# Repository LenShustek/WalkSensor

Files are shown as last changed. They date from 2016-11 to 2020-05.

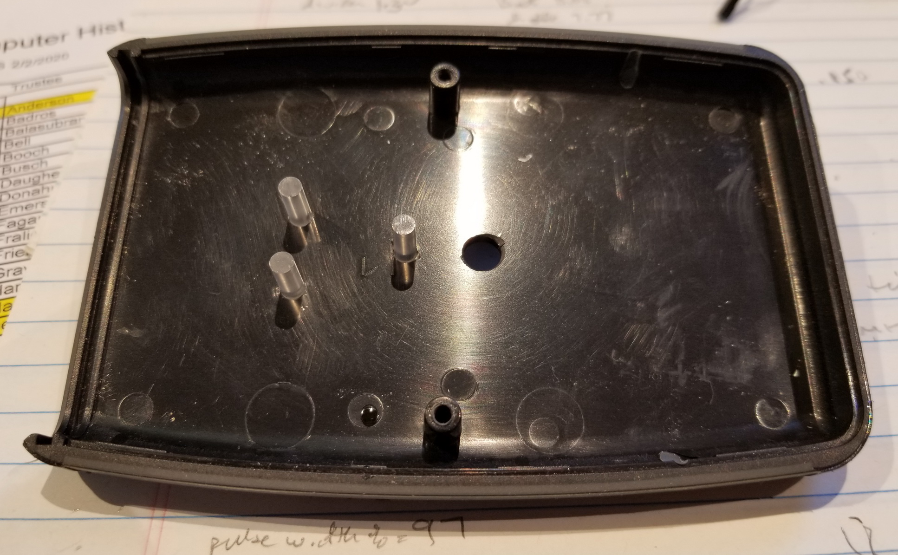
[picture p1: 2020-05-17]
V3/cover.jpg

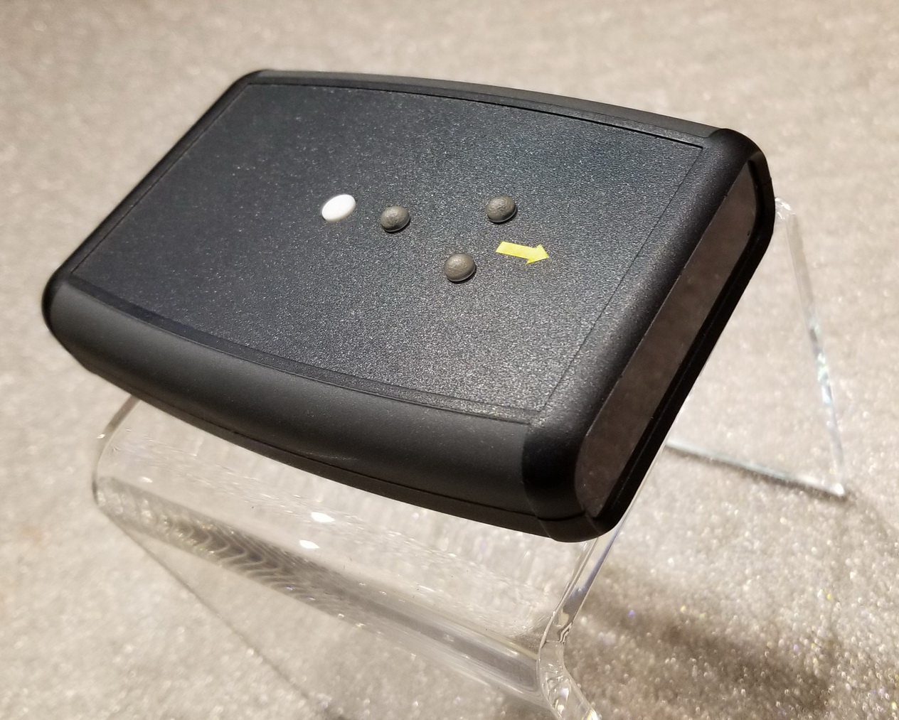
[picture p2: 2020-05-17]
V3/outside_sm.jpg

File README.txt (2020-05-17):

           Battery-powered walk path sensor
 for clinical trials of therapies for movement disorders

  This is a small battery-powered wireless sensor that, when used
  in a pair on opposite sides of a walking path, detects someone
  walking through an IR beam between the sensors. It then sends a
  Bluetooth alert with detailed timing to a mobile phone or tablet.

  The custom-built sensor hardware consist of:
  - an AVR microprocessor
  - a Bluetooth LE radio module
  - 940nm IR LED transmitter powered by a constant-current driver
  - 940nm 38 Khz tuned IR receiver
  - red/green battery status light
  - blue and yellow operational status lights
  - power on/off pushbutton
  - program-controlled power supply circuit
  - enclosure with battery holder

Version 2 in 2017 used the Adafruit Bluefruit Feather 32U4 with an 
integrated Bluetooth module. The board used mostly through-hole 
components, and required tricky alignment of the LEDs into holes in the 
case. It was powered by 4 AA batteries in a rather clunky-looking square 
enclosure. 

Version 3 in 2020 uses a "raw" ATMega328P processor and a Microchip 
RN4870 Bluetooth module. All components are now surface mounted, 
including the LEDs which sit below light pipes in the cover. It is 
powered by a 9V battery in a sleeker case that looks more like a 
remote control.

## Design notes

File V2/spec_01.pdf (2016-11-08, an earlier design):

# Walk sensor

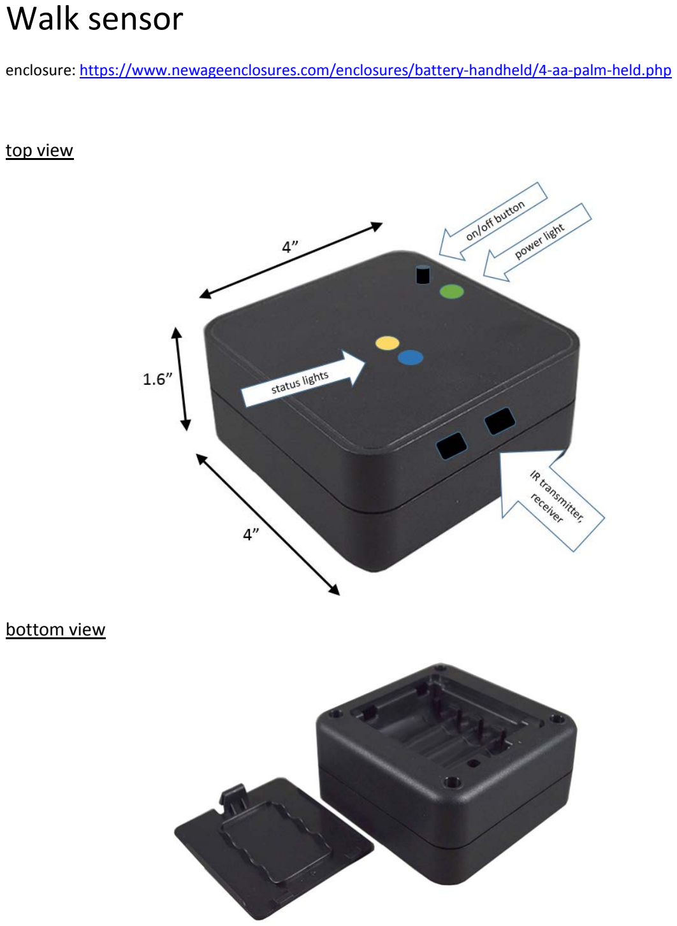
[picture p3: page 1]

enclosure: https://www.newageenclosures.com/enclosures/battery-handheld/4-aa-palm-held.php

top view

bottom view

Operation

- power:
- push the button to turn it on
- battery ok: light continually blinks green (.05s every 5s)
- battery marginal: light continually blinks red (.05s every 5s)
- battery too low: light blinks long red (5x: .5s every 1s), then unit shuts off
- push the button to turn it off
- light blinks red once (.5s), then shuts off
- after 8 hours
- unit turns off automatically
- mode: when the unit turns on, it tries to detect an opposing IR transmitter
- if no IR signal detected, it becomes the IR transmitter
- yellow status light blinks continually (.05s every 1s)
- if an IR signal is detected: it becomes the IR receiver
- when the IR signal is interrupted for >.2s
- blue light turns on until IR signal returns
- send a Bluetooth message (format TBD)

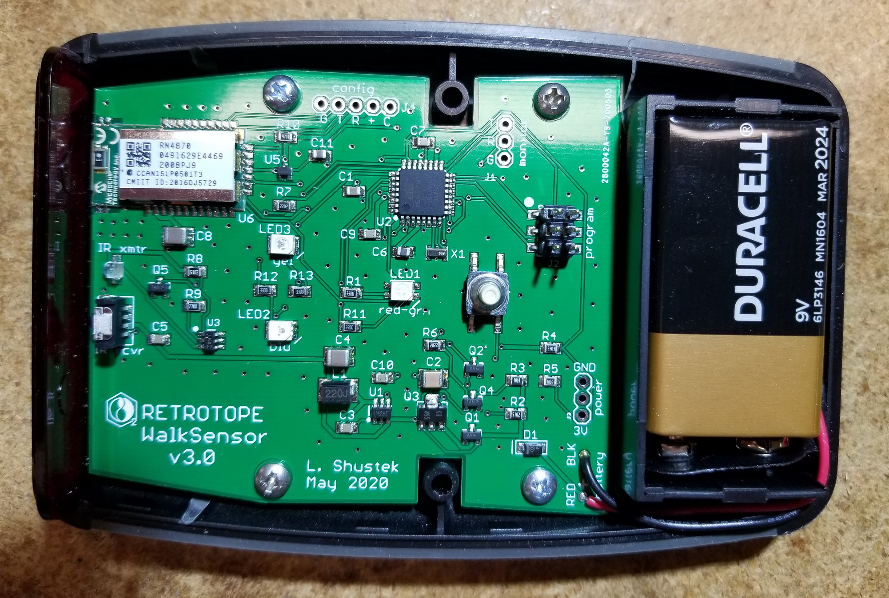
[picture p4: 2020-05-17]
V3/inside_sm.jpg

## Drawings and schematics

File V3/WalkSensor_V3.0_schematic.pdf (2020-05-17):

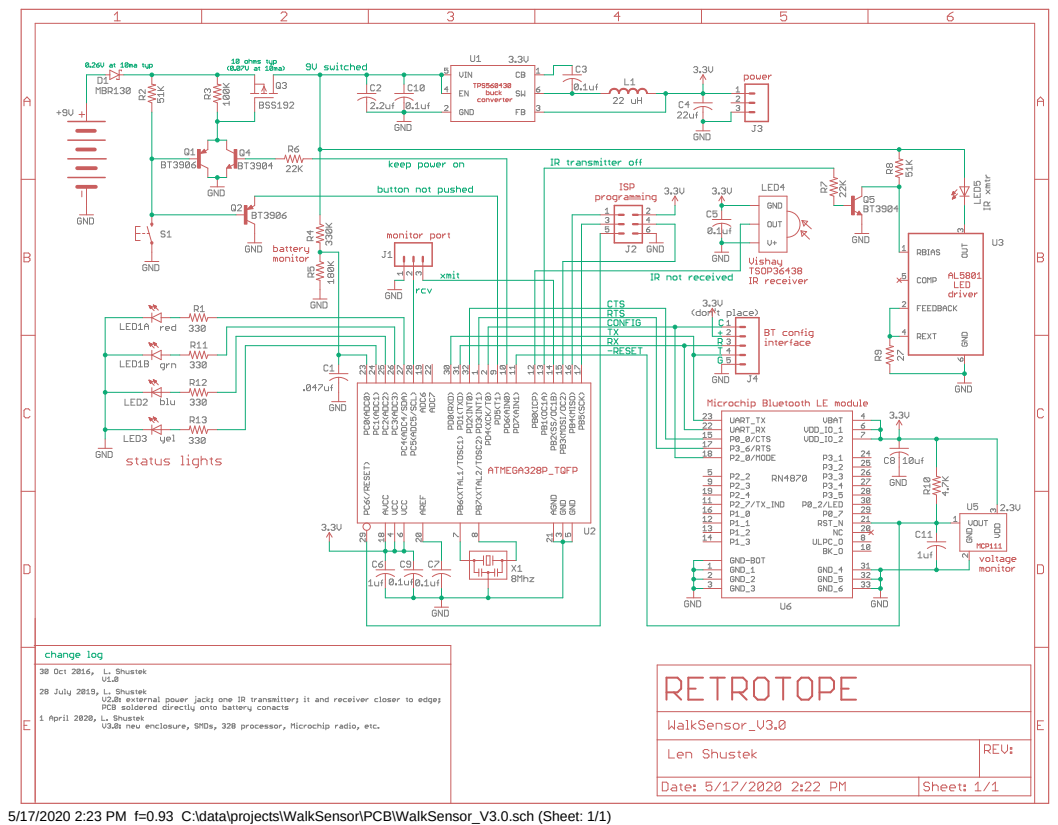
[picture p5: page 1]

5/17/2020 2:23 PM f=0.93 C:\data\projects\WalkSensor\PCB\WalkSensor_V3.0.sch (Sheet: 1/1)

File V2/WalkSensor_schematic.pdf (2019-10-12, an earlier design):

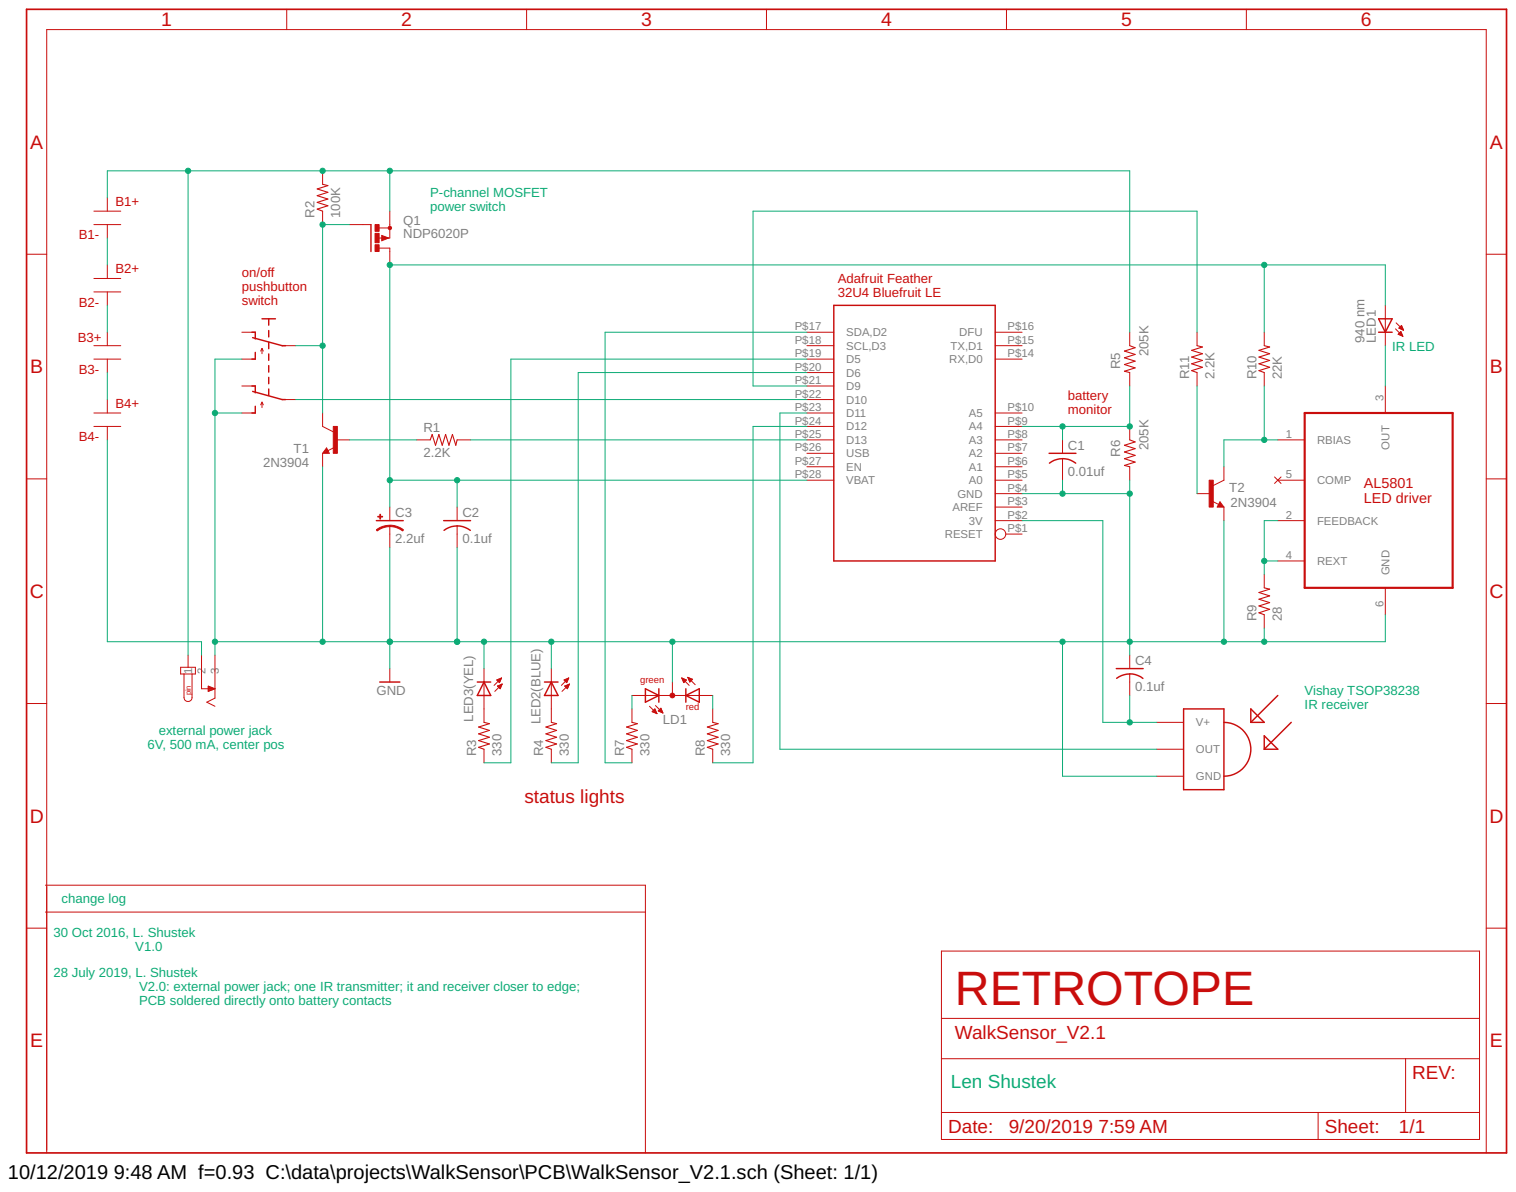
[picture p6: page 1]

Adafruit Feather 32U4 Bluefruit LE

V2.0: external power jack; one IR transmitter; it and receiver closer to edge; PCB soldered directly onto battery contacts

Len Shustek | REV:

Date: 9/20/2019 7:59 AM | Sheet: 1/1

10/12/2019 9:48 AM f=0.93 C:\data\projects\WalkSensor\PCB\WalkSensor_V2.1.sch (Sheet: 1/1)

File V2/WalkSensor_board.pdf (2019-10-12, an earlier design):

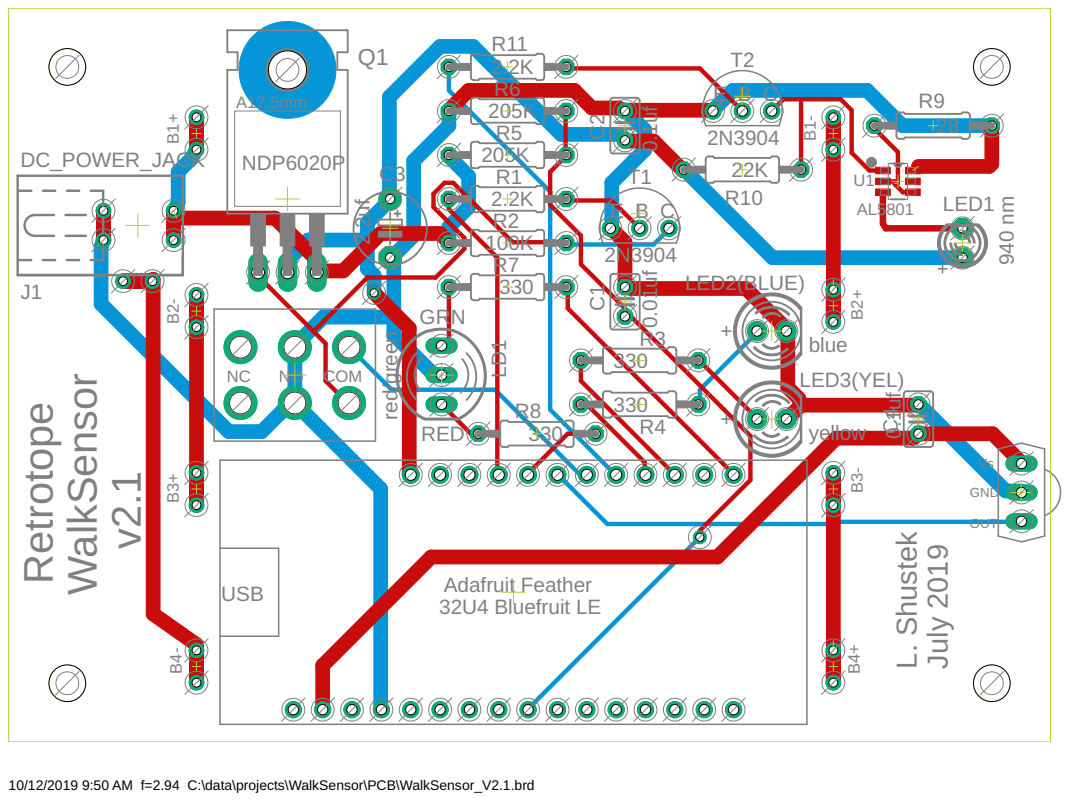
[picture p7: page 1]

10/12/2019 9:50 AM f=2.94 C:\data\projects\WalkSensor\PCB\WalkSensor_V2.1.brd

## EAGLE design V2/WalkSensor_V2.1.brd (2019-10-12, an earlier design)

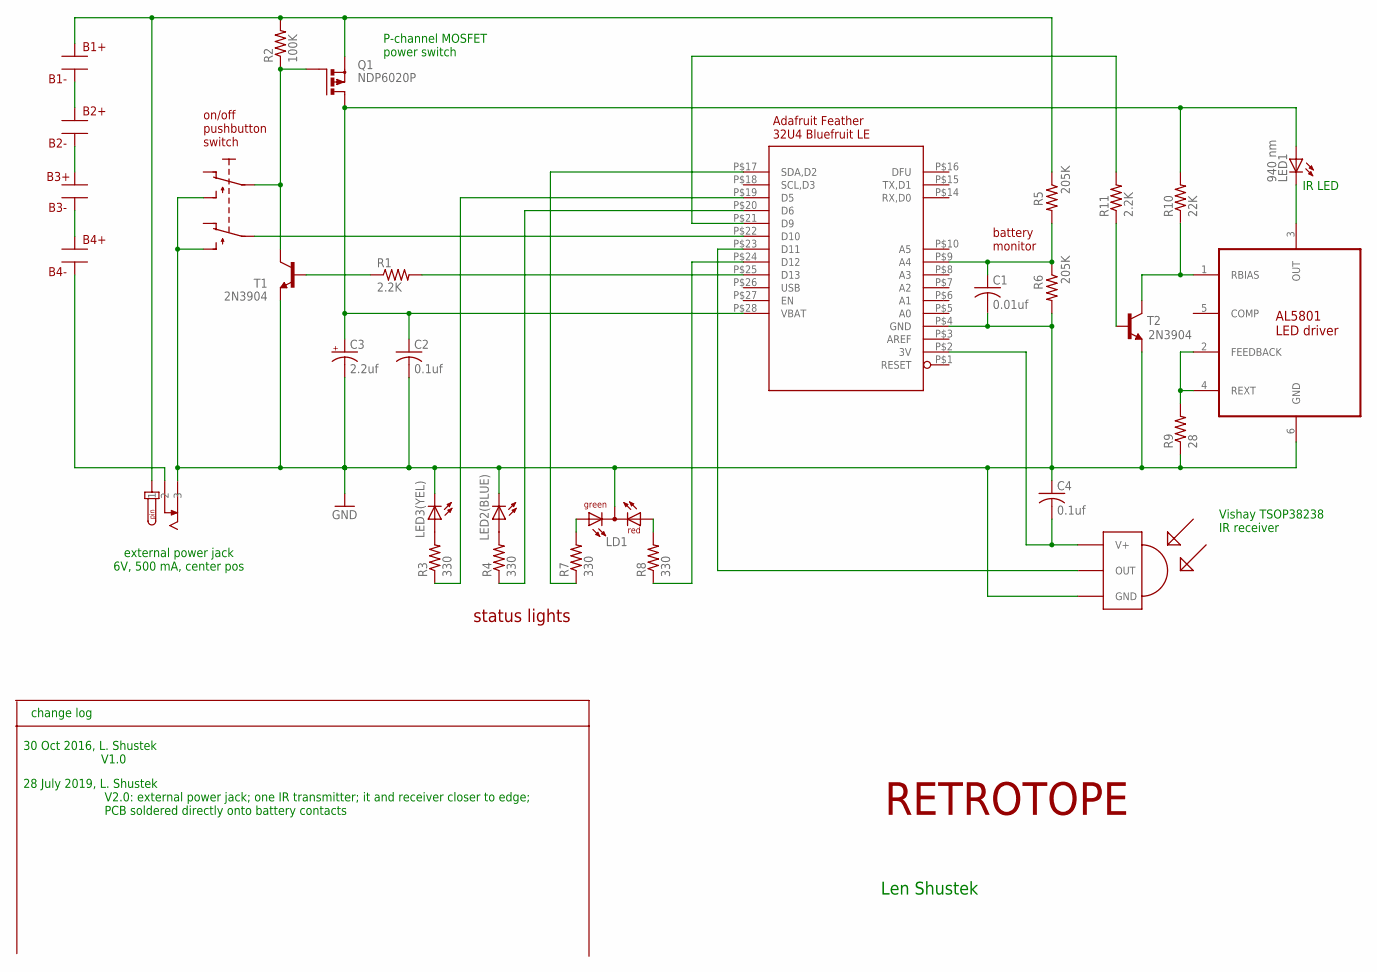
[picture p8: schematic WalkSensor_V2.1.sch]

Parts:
B1+, B1-, B2+, B2-, B3+, B3-, B4+, B4-: BATTERY_CONTACT
C1: 0.01uf; C025-025X050
C2, C4: 0.1uf; C025-025X050
C3: 2.2uf; E5-6
J1: DC_POWER_JACK
LD1: red/green; DUOLED-C-5MM
LED1: 940 nm; LED3MM
LED2(BLUE): blue; LED5MM
LED3(YEL): yellow; LED5MM
Q1: NDP6020P; TO220BH
R1, R11: 2.2K; 0207/10
R2: 100K; 0207/10
R3, R4, R7, R8: 330; 0207/10
R5, R6: 205K; 0207/10
R9: 28; 0207/10
R10: 22K; 0207/10
T1, T2: 2N3904; TO92-EBC
U1: AL5801; SOT95P280X130-6N
U$2: PUSHBUTTON-DPDT
U$3: TSOP1830; TSOP18XX
U$4: BLUEFRUIT-LE

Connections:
3V: C4.2, U$3.VCC (V+), U$4.P$2 (3V)
GND: C1.2, C2.2, C3.-, C4.1, J1.P$5 (3), LD1.C, LED2(BLUE).K (C), LED3(YEL).K (C), R6.2, R9.1, T1.E, T2.E, U1.6 (GND), U$2.P$1 (S), U$2.P$2 (S1), U$3.GND, U$4.P$4 (GND)
unnamed: U$2.P$6 (P1), U$4.P$22 (D10)
unnamed: LED3(YEL).A, R3.2
unnamed: B1+.P$1, J1.P$1 (1), Q1.S, R2.2, R5.1
unnamed: LED2(BLUE).A, R4.2
unnamed: Q1.G, R2.1, T1.C, U$2.P$5
unnamed: R11.1, T2.B
unnamed: R1.2, U$4.P$25 (D13)
unnamed: R1.1, T1.B
unnamed: R4.1, U$4.P$20 (D6)
unnamed: R3.1, U$4.P$19 (D5)
unnamed: LED1.K (C), U1.3 (OUT)
unnamed: R11.2, U$4.P$21 (D9)
unnamed: LD1.AG, R7.2
unnamed: LD1.AR, R8.2
unnamed: B1-.P$1, B2+.P$1
unnamed: R7.1, U$4.P$17 (SDA,D2)
unnamed: B2-.P$1, B3+.P$1
unnamed: U$3.OUT, U$4.P$23 (D11)
unnamed: R9.2, U1.2 (FEEDBACK), U1.4 (REXT)
unnamed: C1.1, R5.2, R6.1, U$4.P$9 (A4)
unnamed: R10.1, T2.C, U1.1 (RBIAS)
unnamed: R8.1, U$4.P$24 (D12)
unnamed: B3-.P$1, B4+.P$1
unnamed: B4-.P$1, J1.P$3 (2)
VBAT: C2.1, C3.+, LED1.A, Q1.D, R10.2, U$4.P$28 (VBAT)

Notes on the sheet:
Vishay TSOP38238 IR receiver
IR LED
P-channel MOSFET power switch
change log
30 Oct 2016, L. Shustek V1.0
Len Shustek
RETROTOPE
status lights
on/off pushbutton switch
battery monitor
Adafruit Feather 32U4 Bluefruit LE
external power jack 6V, 500 mA, center pos
28 July 2019, L. Shustek V2.0: external power jack; one IR transmitter; it and receiver closer to edge; PCB soldered directly onto battery contacts

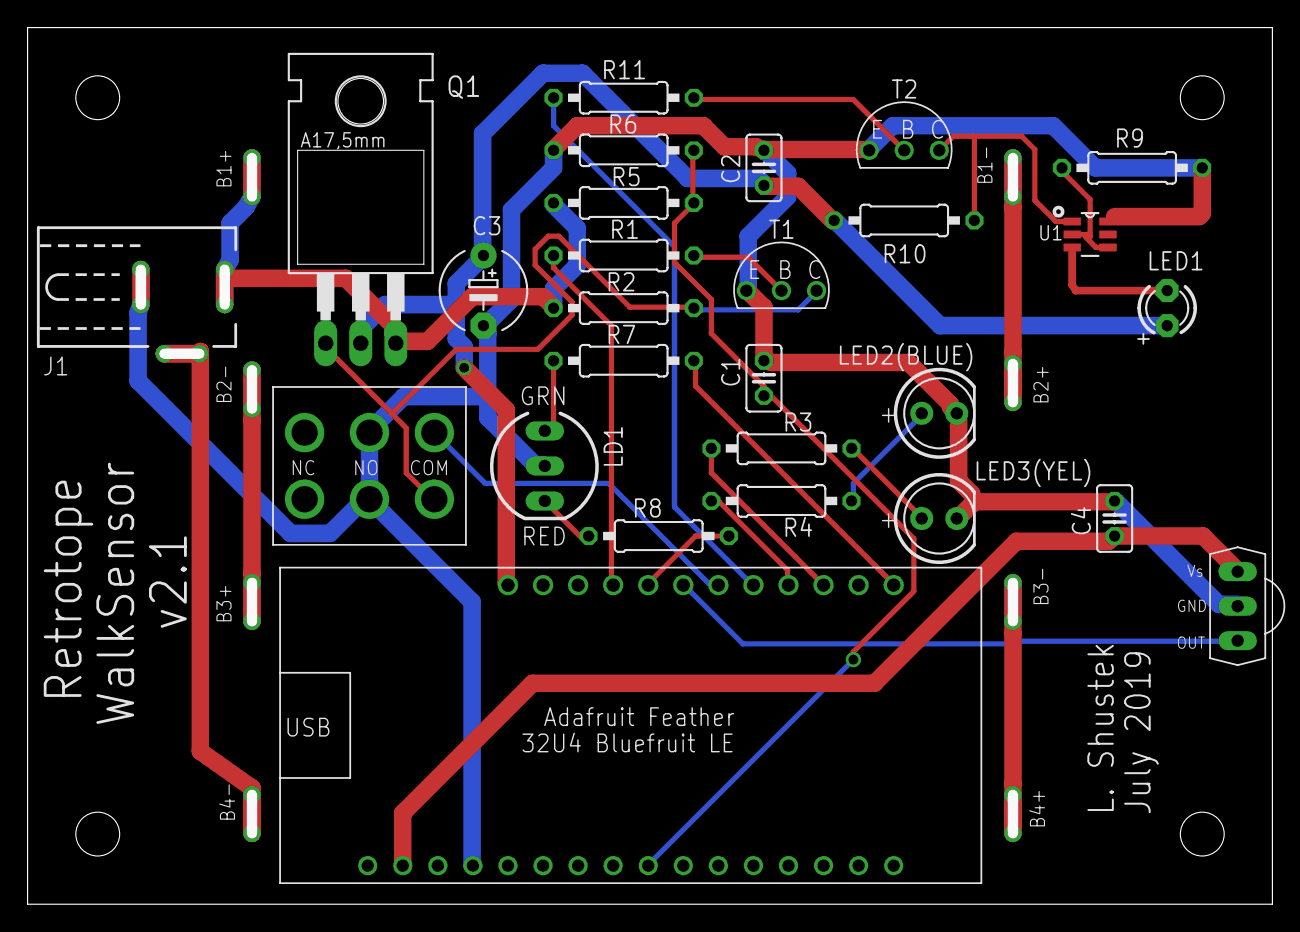
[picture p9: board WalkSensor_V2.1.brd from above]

Board: 2 copper layers, 90.2 x 63.5 mm, 35 parts (0 on the bottom side), 27 nets.

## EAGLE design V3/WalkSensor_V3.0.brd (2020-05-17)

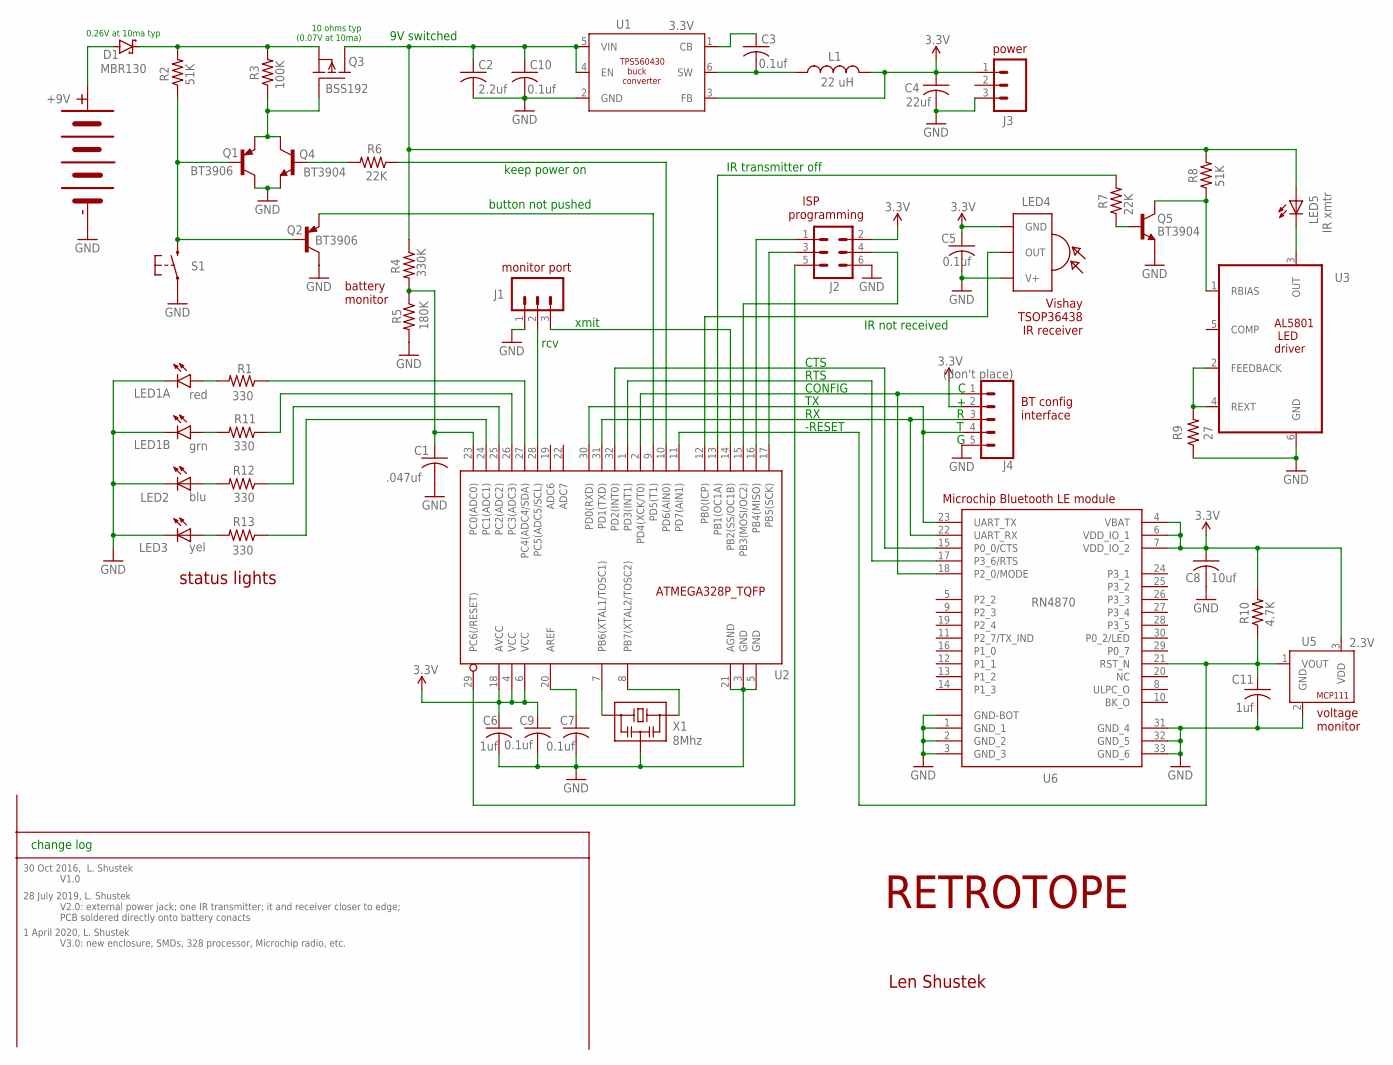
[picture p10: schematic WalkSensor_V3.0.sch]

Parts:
B1: 9V battery wires; 4-CELL-BATTERY
C1: .047uf; C0805
C2: 2.2uf; C1210
C3, C5, C7, C9, C10: 0.1uf; C0805
C4: 22uf; C1210
C6, C11: 1uf; C0805
C8: 10uf; C1210
D1: MBR130; SOD123-2
J1, J3: (don't place); 1X03
J2: ISP pgm connector; 2X3_SMT
J4: (don't place); 1X05
L1: 22 uH; L1812
LED1: red/grn; P-LCC4-1
LED2: blu; LED_PLCC-2
LED3: yel; LED_PLCC-2
LED4: IR rcvr; VISHAY_TSOP_SMD_SIDE
LED5: IR xmtr; LED_VISHAY_VSMB2948
Q1, Q2: BT3906; SOT23-3
Q3: BSS192; SOT89
Q4, Q5: BT3904; SOT23-3
R1, R11, R12, R13: 330; M0805
R2, R8: 51K; M0805
R3: 100K; M0805
R4: 330K; M0805
R5: 180K; M0805
R6, R7: 22K; M0805
R9: 27; M0805
R10: 4.7K; M0805
S1: pushbutton; SWITCH_C&K_GULLWING
U1: 3.3V; SOT23-6
U2: ATMEGA328P_TQFP; TQFP32-08
U3: AL5801; SOT95P280X130-6N
U5: 2.3V; SC70-3-R
U6: RN4870
X1: 8Mhz; CSTNE

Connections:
3.3V: C4.1, C5.1, C6.1, C8.1, C9.1, J2.2, J3.1, J4.2, L1.2, LED4.P$1 (GND), R10.2, U1.3 (FB), U2.4 (VCC), U2.6 (VCC), U2.18 (AVCC), U5.3 (VDD), U6.4 (VBAT), U6.6 (VDD_IO_1), U6.7 (VDD_IO_2)
GND: B1.P$1, C1.2, C2.2, C4.2, C5.2, C6.2, C7.2, C8.2, C9.2, C10.2, C11.2, J1.1, J2.6, J3.3, J4.5, LED1.P$1 (C), LED1.P$4 (C), LED2.P$2 (C), LED3.P$2 (C), LED4.P$3 (V+), Q1.3 (C), Q2.3 (C), Q4.2 (E), Q5.2 (E), R5.2, R9.1, S1.P$1 (1), S1.P$2 (1), U1.2 (GND), U2.3 (GND), U2.5 (GND), U2.21 (AGND), U3.6 (GND), U5.2 (GND), U6.1 (GND_1), U6.2 (GND_2), U6.3 (GND_3), U6.31 (GND_4), U6.32 (GND_5), U6.33 (GND_6), U6.GND (GND-BOT), X1.P$2 (2)
unnamed: C3.1, U1.1 (CB)
unnamed: LED1.P$2 (A), R1.2
unnamed: U2.8 (PB7(XTAL2/TOSC2)), X1.P$3 (3)
unnamed: LED1.P$3 (A), R11.2
unnamed: U2.7 (PB6(XTAL1/TOSC1)), X1.P$1 (1)
unnamed: Q5.1 (B), R7.1
unnamed: D1.P$2 (C), Q3.3 (S), R2.2, R3.2
unnamed: C3.2, L1.1, U1.6 (SW)
unnamed: R1.1, U2.27 (PC4(ADC4/SDA))
unnamed: R11.1, U2.26 (PC3(ADC3))
unnamed: LED5.P$1 (C), U3.3 (OUT)
unnamed: R7.2, U2.13 (PB1(OC1A))
unnamed: LED2.P$1 (A), R12.2
unnamed: LED3.P$1 (A), R13.2
unnamed: J4.3, U2.31 (PD1(TXD)), U6.22 (UART_RX)
unnamed: R12.1, U2.25 (PC2(ADC2))
unnamed: Q1.2 (E), Q3.1 (G), Q4.3 (C), R3.1
unnamed: Q4.1 (B), R6.2
unnamed: R9.2, U3.2 (FEEDBACK), U3.4 (REXT)
unnamed: C1.1, R4.2, R5.1, U2.23 (PC0(ADC0))
unnamed: Q5.3 (C), R8.1, U3.1 (RBIAS)
unnamed: R13.1, U2.24 (PC1(ADC1))
unnamed: Q2.2 (E), U2.9 (PD5(T1))
unnamed: J2.1, U2.16 (PB4(MISO))
unnamed: LED4.P$4 (OUT), U2.12 (PB0(ICP))
unnamed: J2.3, U2.17 (PB5(SCK))
unnamed: J4.4, U2.30 (PD0(RXD)), U6.23 (UART_TX)
unnamed: J1.2, U2.28 (PC5(ADC5/SCL))
unnamed: R6.1, U2.10 (PD6(AIN0))
unnamed: J2.5, U2.29 (PC6(/RESET))
unnamed: J4.1, U2.2 (PD4(XCK/T0)), U6.18 (P2_0/MODE)
unnamed: Q1.1 (B), Q2.1 (B), R2.1, S1.P$3 (3), S1.P$4 (3)
unnamed: J1.3, U2.14 (PB2(SS/OC1B))
unnamed: U2.32 (PD2(INT0)), U6.15 (P0_0/CTS)
unnamed: C7.1, U2.20 (AREF)
unnamed: J2.4, U2.15 (PB3(MOSI/OC2))
unnamed: U2.1 (PD3(INT1)), U6.17 (P3_6/RTS)
unnamed: C11.1, R10.1, U2.11 (PD7(AIN1)), U5.1 (VOUT), U6.21 (RST_N)
unnamed: C2.1, C10.1, LED5.P$2 (A), Q3.2 (D), Q3.2@1 (D), R4.1, R8.2, U1.4 (EN), U1.5 (VIN)
unnamed: B1.P$2, D1.P$1 (A)

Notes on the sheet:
Vishay TSOP36438 IR receiver
change log
30 Oct 2016, L. Shustek V1.0
Len Shustek
RETROTOPE
status lights
battery monitor
28 July 2019, L. Shustek V2.0: external power jack; one IR transmitter; it and receiver closer to edge; PCB soldered directly onto battery conacts
1 April 2020, L. Shustek V3.0: new enclosure, SMDs, 328 processor, Microchip radio, etc.
+9V
ISP programming
monitor port
keep power on
button not pushed
power
BT config interface
CTS
RTS
CONFIG
-RESET
voltage monitor
red
rcv
xmit
0.26V at 10ma typ
10 ohms typ (0.07V at 10ma)
9V switched
IR transmitter off
IR not received
grn
Microchip Bluetooth LE module

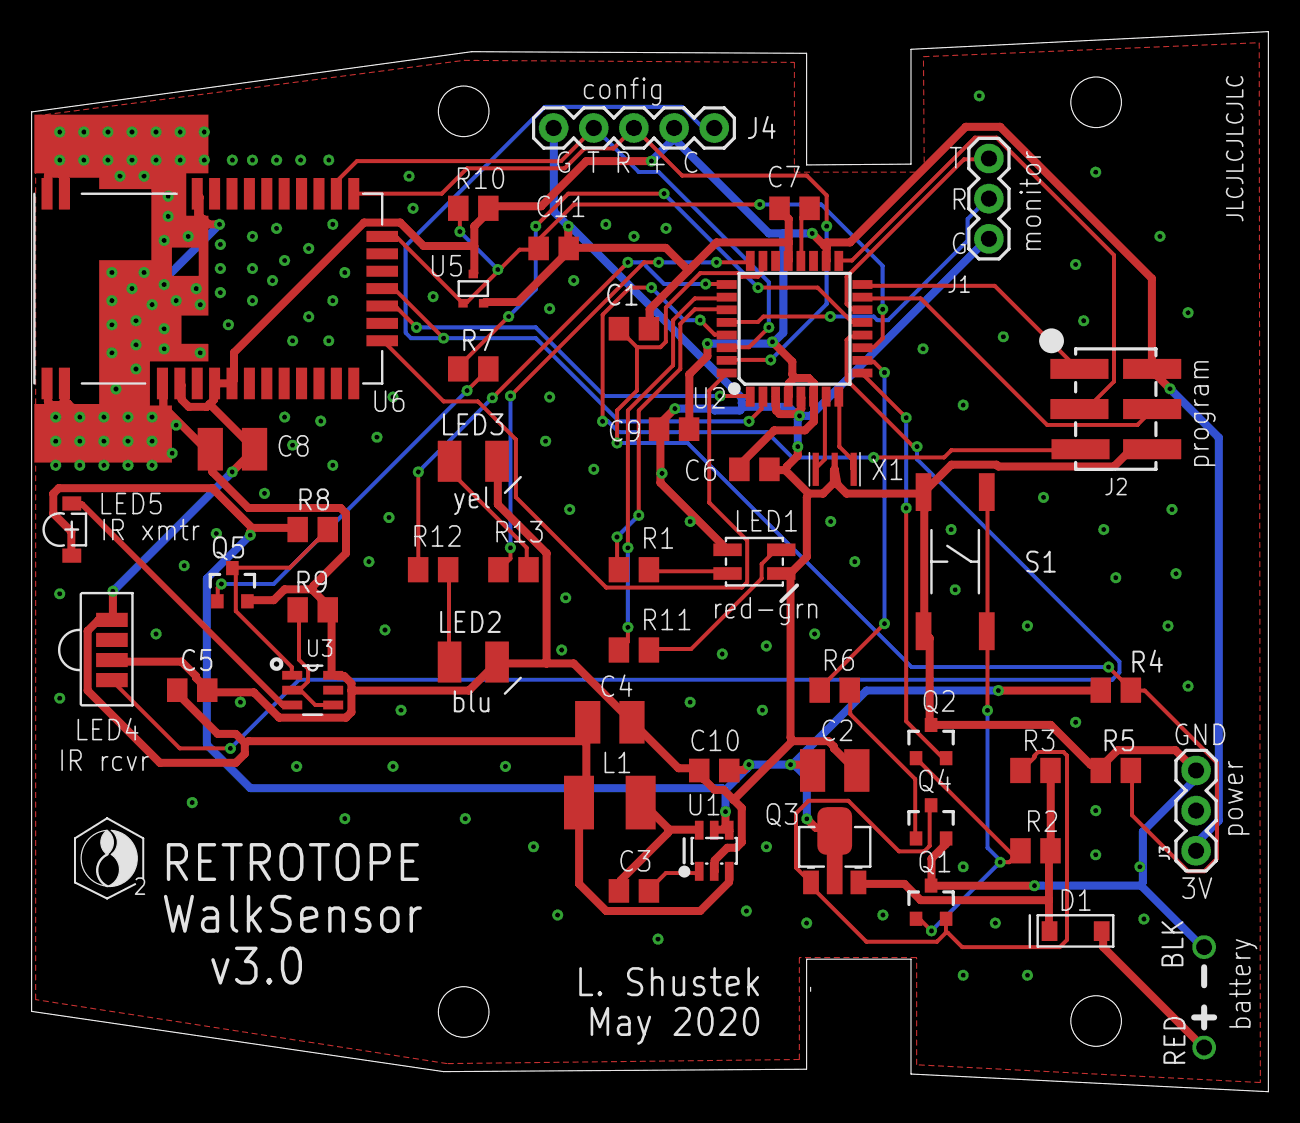
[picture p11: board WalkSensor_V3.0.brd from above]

Board: 2 copper layers, 78.2 x 67.1 mm, 48 parts (0 on the bottom side), 42 nets.

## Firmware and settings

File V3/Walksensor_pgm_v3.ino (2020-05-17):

/***************************************************************************************************

    Battery-powered walk path sensor

   This is the software for a small (4.5" x 3" 1") battery-powered wireless sensor
   that, when used in a pair on opposite sides of a walking path, detects someone
   walking through an IR beam between the sensors. It then sends a Bluetooth alert
   to a mobile phone or tablet.

   This is for version 3, which uses SMD parts.

   The custom-built sensor hardware consist of:
   - AtMega 328P processor, similar to what is in an Arduino UNO
   - Microchip RN4870 Bluetooth LE module
   - 940nm IR LED transmitter powered by a constant-current driver
   - 940nm 38 Khz tuned IR receiver
   - red/green battery status light
   - blue and yellow operational status lights
   - power on/off pushbutton
   - program-controlled power supply circuit
   - battery condition sensor
   - 9V alkaline battery (500 mAh)

   approximate power utilization:
    - when idle: 10 uA, so 4+ years shelf life
    - as an IR transmitter: 6.7 ma, so 60 hours of continuous use (of 80% capacity)
    - as an IR receiver: 6.4 ma, so 62 hours of continuous use (of 80% capacity)

   Operation
    power:
      push the button to turn it on
        all three lights flash
        if battery is marginal, the red light flashes every 5 seconds
        if the battery is too low, all lights flash 5 times and the unit shuts off
      push the button to turn it off
        all three lights flash once, and the unit shuts off
      after 1 hour of no activity, the unit turns off automatically
   mode: when the unit turns on, it tries to detect an opposing IR transmitter
    if no IR signal detected, it becomes the IR transmitter
      - the yellow light flashes every 2 seconds
    if an IR signal is detected: it becomes the IR receiver
      - the blue light flashes every 2 seconds
      - we beacon advertise with the name "retrotope-timer(0)nnnn", where
        nnnn is our timestamp in milliseconds, updated every 250 msec
      - when the IR signal is interrupted,
        - the blue light turns on for 5 seconds
        - we advertise with the name "retrotope-timer(1)nnnn", where
          nnnn is the timestamp in milliseconds at the time the beam broke
      -if the beam break lasts more than 5 seconds,
        - continue the same "retrotope-timer(1)nnnn" advertising
        - flash yellow and blue lights obnoxiously

   special startup modes: hold the button for more than 5 seconds
     - all three lights flash in rotation for a couple of seconds
     - the red light flashes N=1,2,3... times, and then waits for the button
       - if the button is pushed after N flashes, it enters mode N:
         - 1: normal mode, except no power down after one hour
         - 2: normal mode, except flash software version and battery voltage first
         - 3: normal mode, except do a factory reset on the Bluetooth module
              (generally requires a power off/on to recover)
         - 4: special timer sync mode: link two units to compare their clocks
              (needs work for V3)

   The design of the hardware and software for the sensors and the corresponding
   receiver is open-source.  See https://github.com/LenShustek/walksensor.

   Tips for programming the "bare" ATMega328P on our PC board:
    - There is only 2K of RAM, so be frugal allocating array variables!
    - A 2x3 pin header mates to the Pololu USB AVR Programmer v2.1,
      configured with their utility program to supply 3.3V to the target board.
      The red cable stripe goes next to the dot.
    - Select the board "Arduino/Genuino Uno".
    - The boards.txt file in C:\Users\len\AppData\Local\Arduino15\packages\arduino\hardware\avr\1.6.21\...
      has to be changed to allow the frequency to be set to other than 16 Mhz.
        #uno.build.f_cpu=1000000L
        ...
        menu.speed=CPU Speed
        uno.menu.speed.1=1 MHz
        uno.menu.speed.2=2 MHz
        uno.menu.speed.4=4 MHz
        uno.menu.speed.8=8 MHz
        uno.menu.speed.16=16 MHz
        uno.menu.speed.1.build.f_cpu=1000000L
        uno.menu.speed.2.build.f_cpu=2000000L
        uno.menu.speed.4.build.f_cpu=4000000L
        uno.menu.speed.8.build.f_cpu=8000000L
        uno.menu.speed.16.build.f_cpu=16000000L
     (may need to uncheck "aggressively cache compiled core" in files/preferences after changing it?)
     (See https://tttapa.github.io/Pages/Arduino/Bootloaders/ATmega328P-custom-frequency.html)
   - Select the "Atmel STK500 development board" programmer in the Aduino IDE tools/programmer menu.
       Then "Upload using programmer"; it only takes about 10 seconds.
   - Use AVRDUDE to check and modify fuse settings to change the clock.
       avrdude -c stk500v2 -P COM7 -p m328p  (show signature and current fuses)
          avrdude: Device signature = 0x1e950f (probably m328p)
          avrdude: safemode: Fuses OK (E:FF, H:D9, L:62)
      The ATMega328p comes with the low fuse preprogrammed as 0x62, which uses the
      internal RC 8 Mhz ocillator divided by 8, producing a system clock of 1 Mhz.
      We change it to use a more accurate external low-power 8 Mz ceramic resonator, divided by 1,
      with startup time of 1K clocks + 4.1 msec, producing a system clock of 8 Mhz.
      So the low fuse should be FE: 1 (no div by 8), 1 (no ext clk), 11 (startup time), 1110 (clk select)
         avrdude -c stk500v2 -P COM7 -p m328p -U lfuse:w:0xfe:m

   ------------------------------------------------------------------------------------------------------
   Copyright (c) 2016,2020 Len Shustek

                                    The MIT License (MIT)
   Permission is hereby granted, free of charge, to any person obtaining a copy of this software and
   associated documentation files (the "Software"), to deal in the Software without restriction,
   including without limitation the rights to use, copy, modify, merge, publish, distribute,
   sublicense, and/or sell copies of the Software, and to permit persons to whom the Software is
   furnished to do so, subject to the following conditions:

   The above copyright notice and this permission notice shall be included in all copies or
   substantial portions of the Software.

   THE SOFTWARE IS PROVIDED "AS IS", WITHOUT WARRANTY OF ANY KIND, EXPRESS OR IMPLIED, INCLUDING BUT
   NOT LIMITED TO THE WARRANTIES OF MERCHANTABILITY, FITNESS FOR A PARTICULAR PURPOSE AND
   NONINFRINGEMENT. IN NO EVENT SHALL THE AUTHORS OR COPYRIGHT HOLDERS BE LIABLE FOR ANY CLAIM,
   DAMAGES OR OTHER LIABILITY, WHETHER IN AN ACTION OF CONTRACT, TORT OR OTHERWISE, ARISING
   FROM, OUT OF OR IN CONNECTION WITH THE SOFTWARE OR THE USE OR OTHER DEALINGS IN THE SOFTWARE.
   ------------------------------------------------------------------------------------------------------

  **** Change log ****

   31 Oct 2016, V1.0, L. Shustek, First version.
   16 Nov 2017, V1.1, L. Shustek, various enhancements on the way to production
   16 Dec 2017, V1.2, L. Shustek, experiment with transmitting and receiving simultaneously
   27 Dec 2017, V2.0, L. Shustek, experiment with GAP advertisements
   29 Jan 2017, V2.1, L. Shustek, implement GAP advertising protocol;
    1 Feb 2017, V2.2, L. Shustek, Turn off verbose mode in BLE library.
                                  Add special startup modes if button pushed for more than 5 seconds:
                                    #1: normal mode but with no power-down timeout
                                    #2: special timing mode that links two units to compare clock speed
    4 Feb 2017, V2.3, L. Shustek, Look at additional test input (D0/RX) which, when low, is treated
                                  as a beam break.
   29 Feb 2017, V2.4, L. Shustek, Cosmetic changes. (We abandoned dynamically changing from IR receiver
                                  to IR transmitter or vice versa if we think the other unit is the same.)
   10 May 2020, V3.0, L. Shustek, Version 3, with AtMega328 and Microchip RN4870 Bluetooth module

   TODO:
    - experiment with a lower duty cycle for transmit; can it be as reliable?
 *****************************************************************************************************/
#define MAJOR_VERSION 3
#define MINOR_VERSION 0

#define DEBUG false           // output debugging data on the software serial port?
#define BT_SHOWCMDS false     // if debugging, show we show BT commands and responses?
#define MARKLOCATION false    // mark execution locations for scope tracing?
#define EVENTS false          // record events in a circular buffer for debugging?
#define BLUETOOTH true        // is the the Bluetooth module installed?
#define STOP_IF_BAT_LOW true  // refuse to run with really low battery?
#define USE_SLEEP true        // use power-saving sleep during delay?

#include <Arduino.h>
// This also depends on our modified version of wiring.c that fixes millis() to be exact.
// It should be in this sketch directory.

#if DEBUG
   #include "SoftwareSerial.h" // our local version, which doesn't take over all interrupt vectors,
   // so that we can take over port B pin change interrupt at PCINT0 for the IR receiver.
   // The modified versions of SoftwareSerial.cpp and .h should be in this sketch directory.
   /* Because we might issue BT commands when debugging that produce multiple lines of output,
   we also increase the hardware serial receive buffer from 64 to 256 bytes.
   That requires creating the following file in the directory of the platform.txt that is used:
   C:\Users\len\AppData\Local\Arduino15\packages\arduino\hardware\avr\1.8.1\platform.local.txt
   with these two lines:
   compiler.c.extra_flags=-DSERIAL_RX_BUFFER_SIZE=256
   compiler.cpp.extra_flags=-DSERIAL_RX_BUFFER_SIZE=256
   And then restarting the Arduino IDE.  */
   #if SERIAL_RX_BUFFER_SIZE != 256
      buffer size has not been increased!
   #endif
#endif

#define stringify(x) stringifier(x)  // for turning #defined macros into strings
#define stringifier(x) #x

//  timing and other parameters
// The parameters marked * affect the quality of our beam recognition algorithm

#define MINOR_CYCLE 5             //* the minor cycle time in msec
#define IR_XMT_PERIOD 5           //* IR transmit cycle time in milliseconds between bursts
#define IR_RCV_PERIOD 50          //* IR receive sample period in milliseconds
#define IR_ON_USEC 850            //* IR burst transmit time in microseconds
// For the Vishay TSOP364 (new kind), the max burst is 35 cycles, or 921 usec
// For the Vishay TSOP362 (legacy kind), the max burst is 70 cycles, or 1.94 msec
#define IR_RCV_WIDTH_MIN_USEC (IR_ON_USEC-132-30)  //* the minimum pulse width we count (30 usec margin)
#define MISSING_PULSE_THRESHOLD 2 //* how many missing pulses constitute a beam break
#define CHK_RCV_TIME 200          //  how long to wait to see if the other guy is sending, in msec
/* With those values the transmitter sends one 0.85 msec burst every 5 msec, and 
   the receiver recognizes a pulse if it's at least 0.68 msec wide. 
   When initializing we look for 200 msec, during which time we expect to see 40 pulses, 
   and we decide that we're a receiver if we receive at least 20.
   When operating we look for 50 msec, during which time we expect to see 10 pulses,
   and we record a break if we don't see at least 8. */

#define RCV_NAMECHANGE_TIME 250   // how often to change our name timestamp when beam is seen, in msec
#define RCV_BREAK_TIME 5000       // how long to stretch the beam break time to, in msec
#define ADVERTISING_INTERVAL_HEX_MSEC "0032" // 50 msec between advertisements

#define XLED_ON 50                // transmit status LED on time in milliseconds
#define XLED_PERIOD 2000          // transmit status LED cycle time in milliseconds
#define RLED_ON 50                // receive status LED on time in milliseconds
#define RLED_PERIOD 2000          // receive status LED cycle time in milliseconds
#define LLED_ON 300               // lost beaam LED on time in milliseconds
#define LLED_PERIOD 600           // lost beam LED cycle time in milliseconds
#define BLED_ON 50                // battery LED on time in milliseconds
#define BLED_PERIOD 5000          // battery LED cycle time in millliseconds
#define BATTERY_CHK_PERIOD 5000   // battery check time in milliseconds

#define IR_FREQ 38000L            // tuned IR receiver frequency
#define POWERDOWN_MINUTES 60      // after how many minutes to power down automatically
#define DEBOUNCE_DELAY 25         // debounce delay in msec

#define BATTERY_WEAK 8000         // millivolt level (out of 9000) to warn about low battery 
#define BATTERY_FAIL 7000         // millivolt level (out of 9000) to treat as battery failure

// hardware configuration

// Note that some of these pins have their digital input buffers disabled
// in the setup code to save power.

/* The multiple schemes for pin numbering is confusing!
   IDE  port  TQFP pin  use
   A0  PC0      23     battery monitor
   A1  PC1      24     yellow LED
   A2  PC2      25     blue LED
   A3  PC3      26     green LED
   A4  PC4      27     red LED
   A5  PC5      28     debug serial receive (must be PC, or PD, not PB)
   --  ADC6     19     (unusable for digital I/O)
   --  ADC7     22     (unusable for digital I/O)
   0   PD0      30     RxD from Bluetooth module
   1   PD1      31     TxD to Bluetooth module
   2   PD2      32     RTS from Bluetooth module  (unused presently)
   3   PD3      1      CTS from Bluetooth module  (unused presently)
   4   PD4      2      Config to Bluetooth module (unused presently)
   5   PD5      9      "button not pushed" input (also OC0B)
   6   PD6      10     "keep power on" output (also OC0A)
   7   PD7      11     - RESET to Bluetooth module
   8   PB0      12     IR receiver input (causes PB0 pin change interrupt)
   9   PB1      13     IR LED transmit (output of Counter / Timer 1)
   10  PB2      14     debug serial transmit
   11  PB3      15     ISP MOSI
   12  PB4      16     ISP MISO
   13  PB5      17     ISP SCK
   --  PC6      29     ISP CPU reset  */

#define POWERUP_FET 6       // output pin high keeps us powered up by turning the MOSFET on
#define POWERDOWN_SW 5      // this input pin (needs internal pullup) is low if the on/off button is pushed

#define LED_YELLOW A1       // LED pins: active high
#define LED_BLUE A2
#define LED_GREEN A3
#define LED_RED A4

#define IR_TRANSMIT 9      // active low output pin for IR transmit through constant-current LED driver
//.                           This is PB1, but more importantly, the OC1A output for Timer/Counter1.
#define IR_RECEIVE 8       // active low input pin if IR receiver sees 10 or more pulses at 38 Khz
//.                           This must be on port B, C, or D to allow pin-change interrupts.

// Microchip RN4870 Bluetooth LE module pin assignments
#define BT_RX 0            // receive data from BT (its transmit)
#define BT_TX 1            // PD1: xmit data to BT (its receive)
#define BT_TX_PORT PORTD          // data port D using normal address for load/store
#define BT_TX_MASK 0x02           // mask for bit 1
#define BT_RESET 7         // active low reset 
#define BT_RTS 2           // (not used)
#define BT_CTS 3           // (not used)
#define BT_CONFIG 4        // (not used)

#define DEBUG_RX A5        // software serial receive line; must allow pin-change interrupts
#define DEBUG_TX 10        // software serial transmit line

#if MARKLOCATION && !DEBUG          // pin for scope or logic analyzer tracing
   #define LOCATION_MARKER_PIN 10      // PB2, and CAN'T BE USED WITH DEBUG ON!
   #define LOCATION_MARKER_PORT 0x05   // data port B using the 0-based address for SBI/CBI instructions
   #define LOCATION_MARKER_BIT 2       // bit number (not mask) of the scope pin
#endif
//#define TEST_INPUT 2        // active low test input pin to simulate a beam break

#define BATTERY_VOLTAGE A0    // 0..1023 from A-to-D converter from battery voltage divider
#define BATTERY_R_TOP 330     // top battery resistor divider, in Kohms
#define BATTERY_R_BOT 180     // bottom battery resistor divider, in Kohms
#define BATTERY_VDROP_MV 330  // millivolts of drop before the divider: 0.26V Schottky diode + 0.07V MOSFET
#define AREF_MV  3300         // internal analog reference voltage, in millivolts, is VDD
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
void loop() {
   unsigned long timenow;
   unsigned int cycle_msec;

   //**** delay for a minor cycle time

   EVENT(1);
   lowpower_delay(MINOR_CYCLE);
   timenow = millis() - starttime_millis;
   cycle_msec = (unsigned int) (timenow - cycle_time); // how long since the last cycle
   cycle_time = timenow;
   EVENT(2);

   //**** check for auto-powerdown

   if (!no_powerdown && timenow > (unsigned long)POWERDOWN_MINUTES * 60 * 1000) {
      #if DEBUG
      debug_serial.println("auto shutdown");
      #endif
      shutdown(3); }

   //*** check the battery voltage every so often

   if ((battery_time += cycle_msec) >= BATTERY_CHK_PERIOD) {
      EVENT(3);
      voltage = read_battery_voltage();
      #if DEBUG
      show_battery_voltage(voltage);
      #endif
      if (STOP_IF_BAT_LOW && voltage < BATTERY_FAIL) {  // battery failing?
         #if DEBUG
         debug_serial.println("bat fail");
         flash_battery_voltage(voltage);
         #endif
         shutdown(5); }
      battery_time = 0; }

   //**** check for status light changes due

   if (voltage < BATTERY_WEAK) // flash if battery is weak
      update_led (&led_battery, cycle_msec);
   else if (led_battery.led_on) // we were flashing, but it's good now
      stop_led (&led_battery);

   if (receiver) {
      if (rcv_state == RCVSTATE_BEAMSEEN)
         update_led(&led_receiving, cycle_msec);
      else if (rcv_state == RCVSTATE_BEAMWAIT) {
         update_led(&led_beamlost_1, cycle_msec);
         update_led(&led_beamlost_2, cycle_msec); }
      // else RCVSTATE_BEAMBROKEN: do nothing; light is constant blue
   }
   else  update_led(&led_transmitting, cycle_msec);

   //**** check the powerdown pushbutton

   if (digitalRead(POWERDOWN_SW) == LOW) {
      shutdown(1); }

   //**** check for receiver or transmitter IR activity

   if (receiver) {
      EVENT(5);
      ir_rcv_time += cycle_msec;
      if (ir_rcv_time >= IR_RCV_PERIOD) { // end of a receive sampling period
         int last_ir_rcv_time = ir_rcv_time; // remember how long it was
         int last_falling_pulses = falling_pulses; // and how many pulses we saw
         // We start a new sampling period NOW because if we do BT name changes,
         // it takes a long time and we must sample the next period in the meantime.
         falling_pulses = 0;  // start a new sampling period
         ir_rcv_time = 0;
         switch (rcv_state) {  // process the result from the last period
            case RCVSTATE_BEAMSEEN: // we think we're seeing the beam
               if (last_falling_pulses <= last_ir_rcv_time / IR_XMT_PERIOD - MISSING_PULSE_THRESHOLD) { // if we missed at least 2 or so pulses
                  rcv_state = RCVSTATE_BEAMBROKEN;  // "beam break": start a constant timestamp now
                  beam_lost_time = timenow;
                  #if DEBUG
                  debug_serial.print("rcv_time:"); debug_serial.print(last_ir_rcv_time);
                  debug_serial.print(" fall:"); debug_serial.println(last_falling_pulses);
                  #endif
                  BT_set_devname('1', beam_lost_time);
                  digitalWrite(LED_BLUE, HIGH);     // constant blue light
               }
               else { // we are still seeing the beam
                  if (timenow - name_change_time >= RCV_NAMECHANGE_TIME) {
                     name_change_time = timenow;
                     BT_set_devname('0', name_change_time); // change the timestamp in the name
                  } }
               break;
            case RCVSTATE_BEAMBROKEN:  // beam broken: stretch it out to 5 seconds
               if (timenow - beam_lost_time < RCV_BREAK_TIME)  // not end of "stretched" beam lost time
                  break; // just stay in this state
               digitalWrite(LED_BLUE, LOW);    // end of break time: turn off the constant blue light
               rcv_state = RCVSTATE_BEAMWAIT;  // fall into "wait for beam to return" state below
            case RCVSTATE_BEAMWAIT:  // wait for beam to return
               if (last_falling_pulses <= last_ir_rcv_time / IR_XMT_PERIOD - MISSING_PULSE_THRESHOLD) { // if we missed at least 2 or so pulses
                  // beam is still broken, so must be "lost": we'll do special blue/yellow flashing lights
               }
               else { // we've seen the beam return
                  digitalWrite(LED_BLUE, LOW);   // turn off the blue/yellow flashing lights
                  digitalWrite(LED_YELLOW, LOW);
                  rcv_state = RCVSTATE_BEAMSEEN;
                  name_change_time = timenow + RCV_NAMECHANGE_TIME; // setup to change to '0' name soon
               }
               break;
            default: fatal(ERR_13); } } }

   else { // transmitter
      ir_xmt_time += cycle_msec;
      if (ir_xmt_time >= IR_XMT_PERIOD) { // time to output a 38Khz burst from the IR transmitter
         EVENT(7);
         PRR &= ~(1 << PRTIM1);  // make sure Timer/Counter1 is powered up
         TCCR1B = 0;             // but turned off
         TCCR1A = TCCR1C = 0;
         TCNT1 = 0;              // zero the counter to avoid bogus wraparound
         TIMSK1 = 0;             // don't generate interrupts
         OCR1A = F_CPU / IR_FREQ / 2 - 1;  // the compare limit is twice the frequency
         TCCR1A = 0b01000000;    // toggle OC1A on match, CTC mode
         TCCR1B = 0b00001001;    // CTC mode, no prescaling, clk/1, GO!
         delayMicroseconds(IR_ON_USEC);
         TCCR1B = 0;             // turn off the timer
         TCCR1A = 0;
         digitalWrite(IR_TRANSMIT, HIGH); // leave with the transmitter disabled
         EVENT(8);
         ir_xmt_time = 0; } } }
//*

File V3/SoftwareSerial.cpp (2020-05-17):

//LJS: marks my changes to interrupt vector assignments
/*
SoftwareSerial.cpp (formerly NewSoftSerial.cpp) - 
Multi-instance software serial library for Arduino/Wiring
-- Interrupt-driven receive and other improvements by ladyada
   (http://ladyada.net)
-- Tuning, circular buffer, derivation from class Print/Stream,
   multi-instance support, porting to 8MHz processors,
   various optimizations, PROGMEM delay tables, inverse logic and 
   direct port writing by Mikal Hart (http://www.arduiniana.org)
-- Pin change interrupt macros by Paul Stoffregen (http://www.pjrc.com)
-- 20MHz processor support by Garrett Mace (http://www.macetech.com)
-- ATmega1280/2560 support by Brett Hagman (http://www.roguerobotics.com/)

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
The latest version of this library can always be found at
http://arduiniana.org.
*/

// When set, _DEBUG co-opts pins 11 and 13 for debugging with an
// oscilloscope or logic analyzer.  Beware: it also slightly modifies
// the bit times, so don't rely on it too much at high baud rates
#define _DEBUG 0
#define _DEBUG_PIN1 11
#define _DEBUG_PIN2 13
// 
// Includes
// 
#include <avr/interrupt.h>
#include <avr/pgmspace.h>
#include <Arduino.h>
#include "SoftwareSerial.h"  //LJS: use our local copy
#include <util/delay_basic.h>

//
// Statics
//
SoftwareSerial *SoftwareSerial::active_object = 0;
uint8_t SoftwareSerial::_receive_buffer[_SS_MAX_RX_BUFF]; 
volatile uint8_t SoftwareSerial::_receive_buffer_tail = 0;
volatile uint8_t SoftwareSerial::_receive_buffer_head = 0;

//
// Debugging
//
// This function generates a brief pulse
// for debugging or measuring on an oscilloscope.
#if _DEBUG
inline void DebugPulse(uint8_t pin, uint8_t count)
{
  volatile uint8_t *pport = portOutputRegister(digitalPinToPort(pin));

  uint8_t val = *pport;
  while (count--)
  {
    *pport = val | digitalPinToBitMask(pin);
    *pport = val;
  }
}
#else
inline void DebugPulse(uint8_t, uint8_t) {}
#endif

//
// Private methods
//

/* static */ 
inline void SoftwareSerial::tunedDelay(uint16_t delay) { 
  _delay_loop_2(delay); // in delay_basic.h; loop of 4 cycles per interation
}

// This function sets the current object as the "listening"
// one and returns true if it replaces another 
bool SoftwareSerial::listen()
{
  if (!_rx_delay_stopbit)
    return false;

  if (active_object != this)
  {
    if (active_object)
      active_object->stopListening();

    _buffer_overflow = false;
    _receive_buffer_head = _receive_buffer_tail = 0;
    active_object = this;

    setRxIntMsk(true);
    return true;
  }

  return false;
}

// Stop listening. Returns true if we were actually listening.
bool SoftwareSerial::stopListening()
{
  if (active_object == this)
  {
    setRxIntMsk(false);
    active_object = NULL;
    return true;
  }
  return false;
}

//
// The receive routine called by the interrupt handler
//
void SoftwareSerial::recv()
{

#if GCC_VERSION < 40302
// Work-around for avr-gcc 4.3.0 OSX version bug
// Preserve the registers that the compiler misses
// (courtesy of Arduino forum user *etracer*)
  asm volatile(
    "push r18 \n\t"
    "push r19 \n\t"
    "push r20 \n\t"
    "push r21 \n\t"
    "push r22 \n\t"
    "push r23 \n\t"
    "push r26 \n\t"
    "push r27 \n\t"
    ::);
#endif  

  uint8_t d = 0;

  // If RX line is high, then we don't see any start bit
  // so interrupt is probably not for us
  if (_inverse_logic ? rx_pin_read() : !rx_pin_read())
  {
    // Disable further interrupts during reception, this prevents
    // triggering another interrupt directly after we return, which can
    // cause problems at higher baudrates.
    setRxIntMsk(false);

    // Wait approximately 1/2 of a bit width to "center" the sample
    tunedDelay(_rx_delay_centering);
    DebugPulse(_DEBUG_PIN2, 1);

    // Read each of the 8 bits
    for (uint8_t i=8; i > 0; --i)
    {
      tunedDelay(_rx_delay_intrabit);
      d >>= 1;
      DebugPulse(_DEBUG_PIN2, 1);
      if (rx_pin_read())
        d |= 0x80;
    }

    if (_inverse_logic)
      d = ~d;

    // if buffer full, set the overflow flag and return
    uint8_t next = (_receive_buffer_tail + 1) % _SS_MAX_RX_BUFF;
    if (next != _receive_buffer_head)
    {
      // save new data in buffer: tail points to where byte goes
      _receive_buffer[_receive_buffer_tail] = d; // save new byte
      _receive_buffer_tail = next;
    } 
    else 
    {
      DebugPulse(_DEBUG_PIN1, 1);
      _buffer_overflow = true;
    }

    // skip the stop bit
    tunedDelay(_rx_delay_stopbit);
    DebugPulse(_DEBUG_PIN1, 1);

    // Re-enable interrupts when we're sure to be inside the stop bit
    setRxIntMsk(true);

  }

#if GCC_VERSION < 40302
// Work-around for avr-gcc 4.3.0 OSX version bug
// Restore the registers that the compiler misses
  asm volatile(
    "pop r27 \n\t"
    "pop r26 \n\t"
    "pop r23 \n\t"
    "pop r22 \n\t"
    "pop r21 \n\t"
    "pop r20 \n\t"
    "pop r19 \n\t"
    "pop r18 \n\t"
    ::);
#endif
}

uint8_t SoftwareSerial::rx_pin_read()
{
  return *_receivePortRegister & _receiveBitMask;
}

//
// Interrupt handling
//

/* static */
inline void SoftwareSerial::handle_interrupt()
{
  if (active_object)
  {
    active_object->recv();
  }
}


#if defined(PCINT1_vect)  // LJS Changed from PCINT0 to PCINT1,
ISR(PCINT1_vect)          // LJS since Rx is on PC5
{
  SoftwareSerial::handle_interrupt();
}
#endif

#if 0 //LJS: don't take over vectors we don't use
#if defined(PCINT1_vect)
ISR(PCINT1_vect, ISR_ALIASOF(PCINT0_vect));
#endif

#if defined(PCINT2_vect)
ISR(PCINT2_vect, ISR_ALIASOF(PCINT0_vect));
#endif

#if defined(PCINT3_vect)
ISR(PCINT3_vect, ISR_ALIASOF(PCINT0_vect));
#endif
#endif //LJS

//
// Constructor
//
SoftwareSerial::SoftwareSerial(uint8_t receivePin, uint8_t transmitPin, bool inverse_logic /* = false */) : 
  _rx_delay_centering(0),
  _rx_delay_intrabit(0),
  _rx_delay_stopbit(0),
  _tx_delay(0),
  _buffer_overflow(false),
  _inverse_logic(inverse_logic)
{
  setTX(transmitPin);
  setRX(receivePin);
}

//
// Destructor
//
SoftwareSerial::~SoftwareSerial()
{
  end();
}

void SoftwareSerial::setTX(uint8_t tx)
{
  // First write, then set output. If we do this the other way around,
  // the pin would be output low for a short while before switching to
  // output high. Now, it is input with pullup for a short while, which
  // is fine. With inverse logic, either order is fine.
  digitalWrite(tx, _inverse_logic ? LOW : HIGH);
  pinMode(tx, OUTPUT);
  _transmitBitMask = digitalPinToBitMask(tx);
  uint8_t port = digitalPinToPort(tx);
  _transmitPortRegister = portOutputRegister(port);
}

void SoftwareSerial::setRX(uint8_t rx)
{
  pinMode(rx, INPUT);
  if (!_inverse_logic)
    digitalWrite(rx, HIGH);  // pullup for normal logic!
  _receivePin = rx;
  _receiveBitMask = digitalPinToBitMask(rx);
  uint8_t port = digitalPinToPort(rx);
  _receivePortRegister = portInputRegister(port);
}

uint16_t SoftwareSerial::subtract_cap(uint16_t num, uint16_t sub) {
  if (num > sub)
    return num - sub;
  else
    return 1;
}
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

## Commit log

2019-10-12 update to version 2
    [WalkSensor_V2.1.brd, WalkSensor_V2.1.sch]
2020-05-17 Added V2 to reorganized repository
    [WalkSensor_V2.1.brd, WalkSensor_V2.1.sch, WalkSensor_V3.0.brd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]

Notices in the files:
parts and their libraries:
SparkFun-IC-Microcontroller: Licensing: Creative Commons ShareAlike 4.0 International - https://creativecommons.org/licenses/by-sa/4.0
